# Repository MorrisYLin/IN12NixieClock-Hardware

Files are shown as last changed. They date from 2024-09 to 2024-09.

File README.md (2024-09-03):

# IN-12A Nixie Clock Project
## Overview
This PCB contains driver circuitry to handle high-voltage nixie tubes, which allows for binary-coded decimal to select the lit digit and independent PWM dimming for each tube. It also handles power conversion from a 12V 2A wall adapter to 170V, 5V, and 3.3V rails for the nixie tubes, development board, and ICs respectively, and accomodates connections to an ESP8266 WiFi module and an EK-TM4C1294XL development board from TI. These were chosen due to their relevance in my courses, and the design may be easily adapted to smaller microcontrollers more fitting for a clock.
## Images
Final Result


Front Copper

FrontCu
Back Copper

BackCu
Main Schematic

NixieSchematic
Tube Driver Schematic

TubeController

3D Render
3DRender

## Files
All design was done through KiCAD 8.0, the `TaylorElectronics` folder includes the footprints & symbols for the TES High-voltage power supply as well as others that are not included in the KiCAD standard library. The `nixies_us` folder contains footprints and symbols for the nixie tubes, credit to [judge2005](https://github.com/judge2005/Eagle-and-KiCAD-Nixie-Libs/tree/master) from nixies.us.

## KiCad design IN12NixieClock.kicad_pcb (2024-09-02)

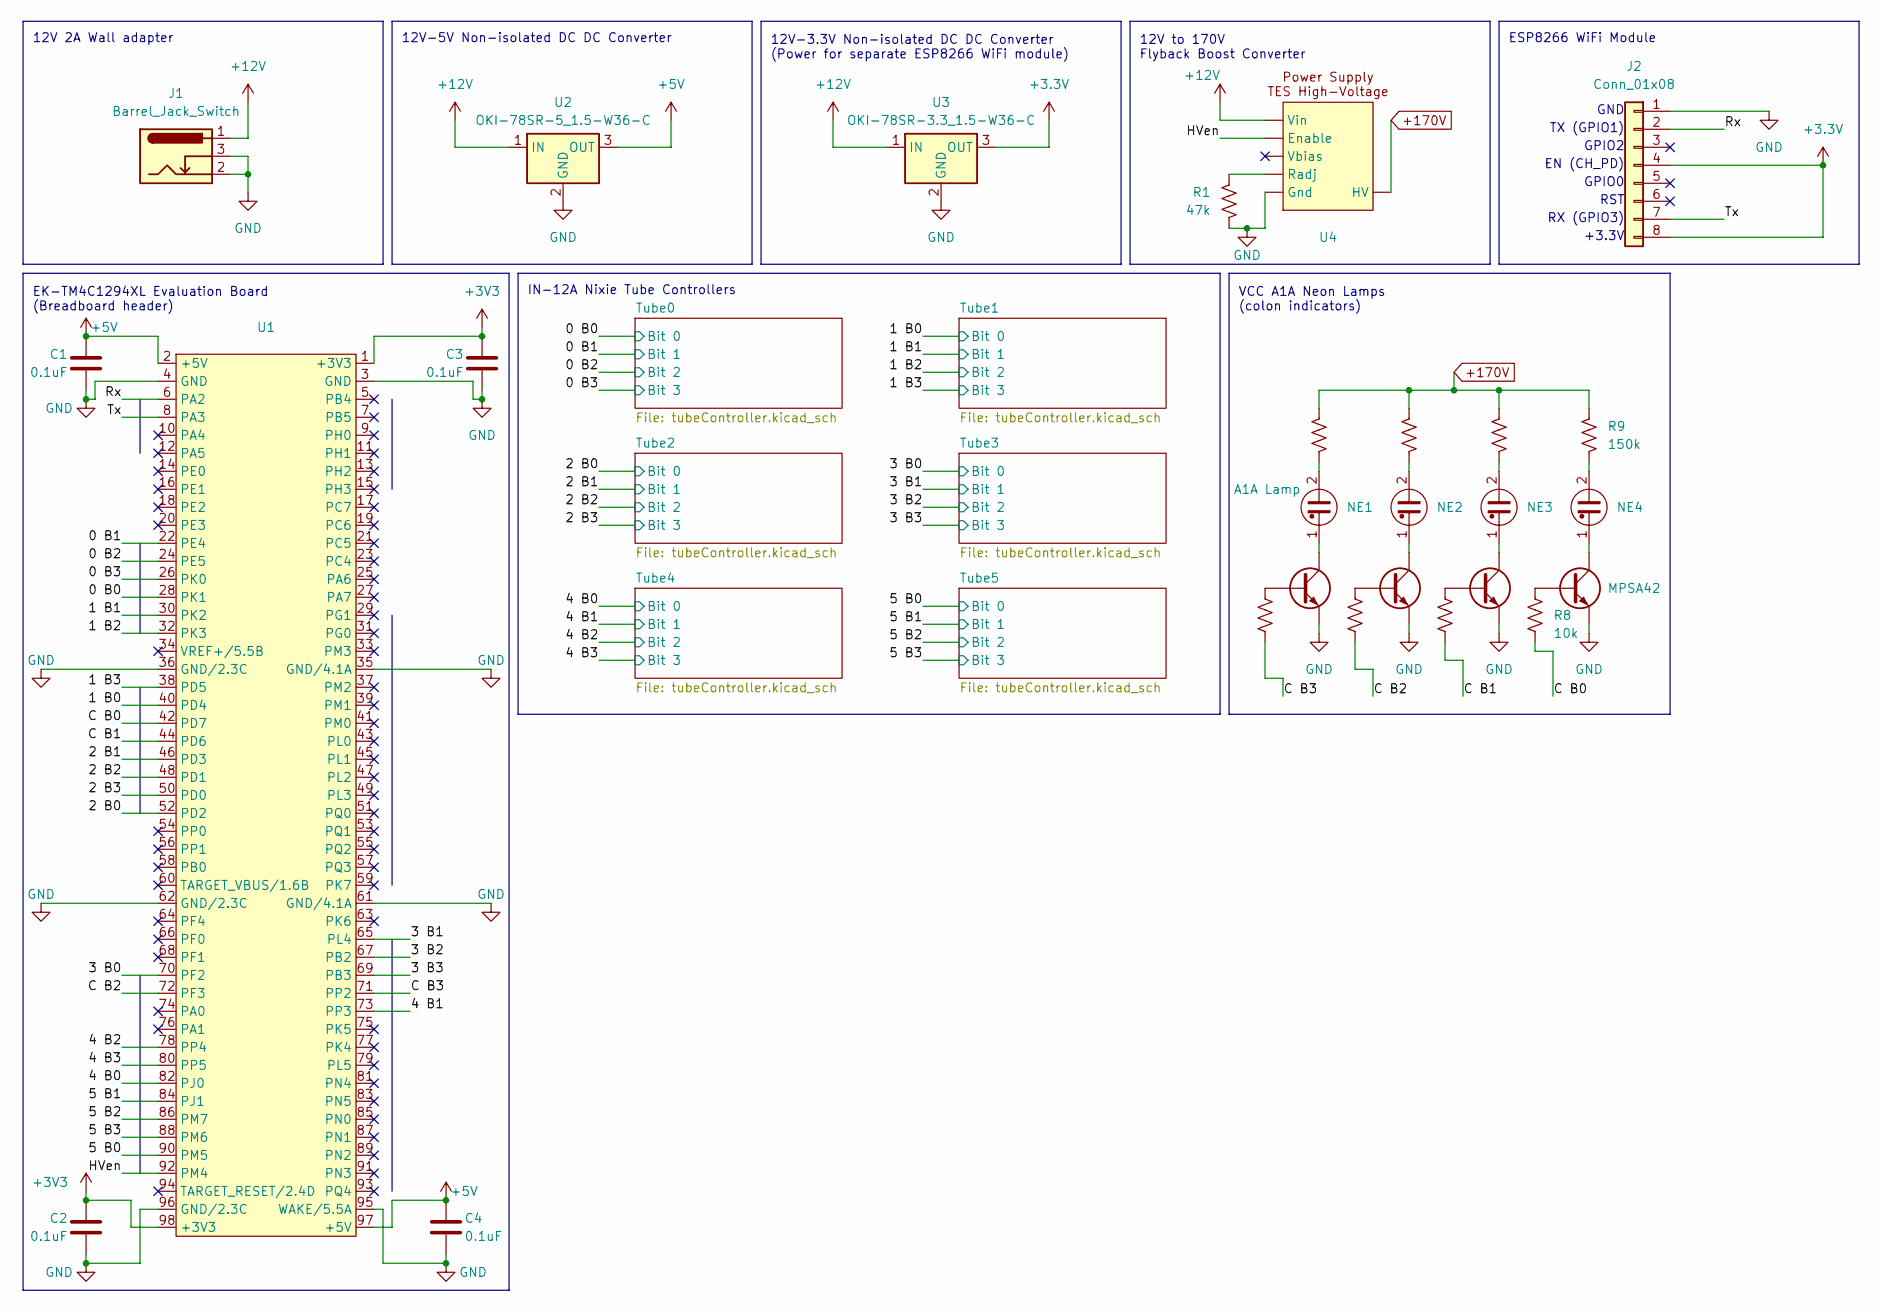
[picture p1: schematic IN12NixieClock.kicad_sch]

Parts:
C1, C2, C3, C4: 0.1uF; C_Disc_D5.0mm_W2.5mm_P5.00mm
J1: Barrel_Jack_Switch; 694106301002_1
J2: Conn_01x08; PinSocket_2x04_P2.54mm_Vertical
NE1: A1A Lamp; PinHeader_1x02_P2.54mm_Vertical
NE2, NE3, NE4: Lamp_Neon; PinHeader_1x02_P2.54mm_Vertical
Q1, Q2, Q3, Q4: MPSA42; TO-92_Inline
R1: 47k; R_Axial_DIN0309_L9.0mm_D3.2mm_P12.70mm_Horizontal
R2, R4, R6, R8: 10k; R_Axial_DIN0204_L3.6mm_D1.6mm_P5.08mm_Horizontal
R3, R5, R7, R9: 150k; R_Axial_DIN0309_L9.0mm_D3.2mm_P12.70mm_Horizontal
U1: X11 Breadboard Adapter Interface
U2: OKI-78SR-5_1.5-W36-C; Converter_DCDC_Murata_OKI-78SR_Vertical
U3: OKI-78SR-3.3_1.5-W36-C; Converter_DCDC_Murata_OKI-78SR_Vertical
U4: TES 1363 HVPS Vertical

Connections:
+3.3V: J2.4, J2.8, U3.3 (OUT); also elsewhere on the board
+3V3: C2.1, C3.1, U1.1 (+3V3), U1.98 (+3V3)
+5V: C1.1, C4.1, U1.2 (+5V), U1.97 (+5V), U2.3 (OUT)
+12V: J1.1, U2.1 (IN), U3.1 (IN), U4.Vin
+170V: R3.1, R5.1, R7.1, R9.1, U4.HV; also elsewhere on the board
/0 B0: U1.28 (PK1); also elsewhere on the board
/0 B1: U1.22 (PE4); also elsewhere on the board
/0 B2: U1.24 (PE5); also elsewhere on the board
/0 B3: U1.26 (PK0); also elsewhere on the board
/1 B0: U1.40 (PD4); also elsewhere on the board
/1 B1: U1.30 (PK2); also elsewhere on the board
/1 B2: U1.32 (PK3); also elsewhere on the board
/1 B3: U1.38 (PD5); also elsewhere on the board
/2 B0: U1.52 (PD2); also elsewhere on the board
/2 B1: U1.46 (PD3); also elsewhere on the board
/2 B2: U1.48 (PD1); also elsewhere on the board
/2 B3: U1.50 (PD0); also elsewhere on the board
/3 B0: U1.70 (PF2); also elsewhere on the board
/3 B1: U1.65 (PL4); also elsewhere on the board
/3 B2: U1.67 (PB2); also elsewhere on the board
/3 B3: U1.69 (PB3); also elsewhere on the board
/4 B0: U1.82 (PJ0); also elsewhere on the board
/4 B1: U1.73 (PP3); also elsewhere on the board
/4 B2: U1.78 (PP4); also elsewhere on the board
/4 B3: U1.80 (PP5); also elsewhere on the board
/5 B0: U1.90 (PM5); also elsewhere on the board
/5 B1: U1.84 (PJ1); also elsewhere on the board
/5 B2: U1.86 (PM7); also elsewhere on the board
/5 B3: U1.88 (PM6); also elsewhere on the board
/C B0: R8.2, U1.42 (PD7)
/C B1: R6.2, U1.44 (PD6)
/C B2: R4.2, U1.72 (PF3)
/C B3: R2.2, U1.71 (PP2)
/HVen: U1.92 (PM4), U4.Enable
/Rx: J2.2, U1.6 (PA2)
/Tx: J2.7, U1.8 (PA3)
GND: C1.2, C2.2, C3.2, C4.2, J1.2, J1.3, J2.1, Q1.1 (E), Q2.1 (E), Q3.1 (E), Q4.1 (E), R1.1, U1.3 (GND), U1.4 (GND), U1.35 (GND/4.1A), U1.36 (GND/2.3C), U1.61 (GND/4.1A), U1.62 (GND/2.3C), U1.95 (WAKE/5.5A), U1.96 (GND/2.3C), U2.2 (GND), U3.2 (GND), U4.Gnd; also elsewhere on the board
unnamed: NE1.2, R3.2
unnamed: NE2.2, R5.2
unnamed: NE3.2, R7.2
unnamed: NE4.2, R9.2
unnamed: Q1.2 (B), R2.1
unnamed: NE1.1, Q1.3 (C)
unnamed: Q2.2 (B), R4.1
unnamed: NE2.1, Q2.3 (C)
unnamed: Q3.2 (B), R6.1
unnamed: NE3.1, Q3.3 (C)
unnamed: Q4.2 (B), R8.1
unnamed: NE4.1, Q4.3 (C)
unnamed: R1.2, U4.Radj

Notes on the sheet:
GND
TX (GPIO1)
GPIO2
RX (GPIO3)
12V to 170V Flyback Boost Converter
IN-12A Nixie Tube Controllers
+3.3V
ESP8266 WiFi Module
EN (CH_PD)
EK-TM4C1294XL Evaluation Board (Breadboard header)
GPIO0
12V 2A Wall adapter
12V-5V Non-isolated DC DC Converter
RST
12V-3.3V Non-isolated DC DC Converter (Power for separate ESP8266 WiFi module)
VCC A1A Neon Lamps (colon indicators)

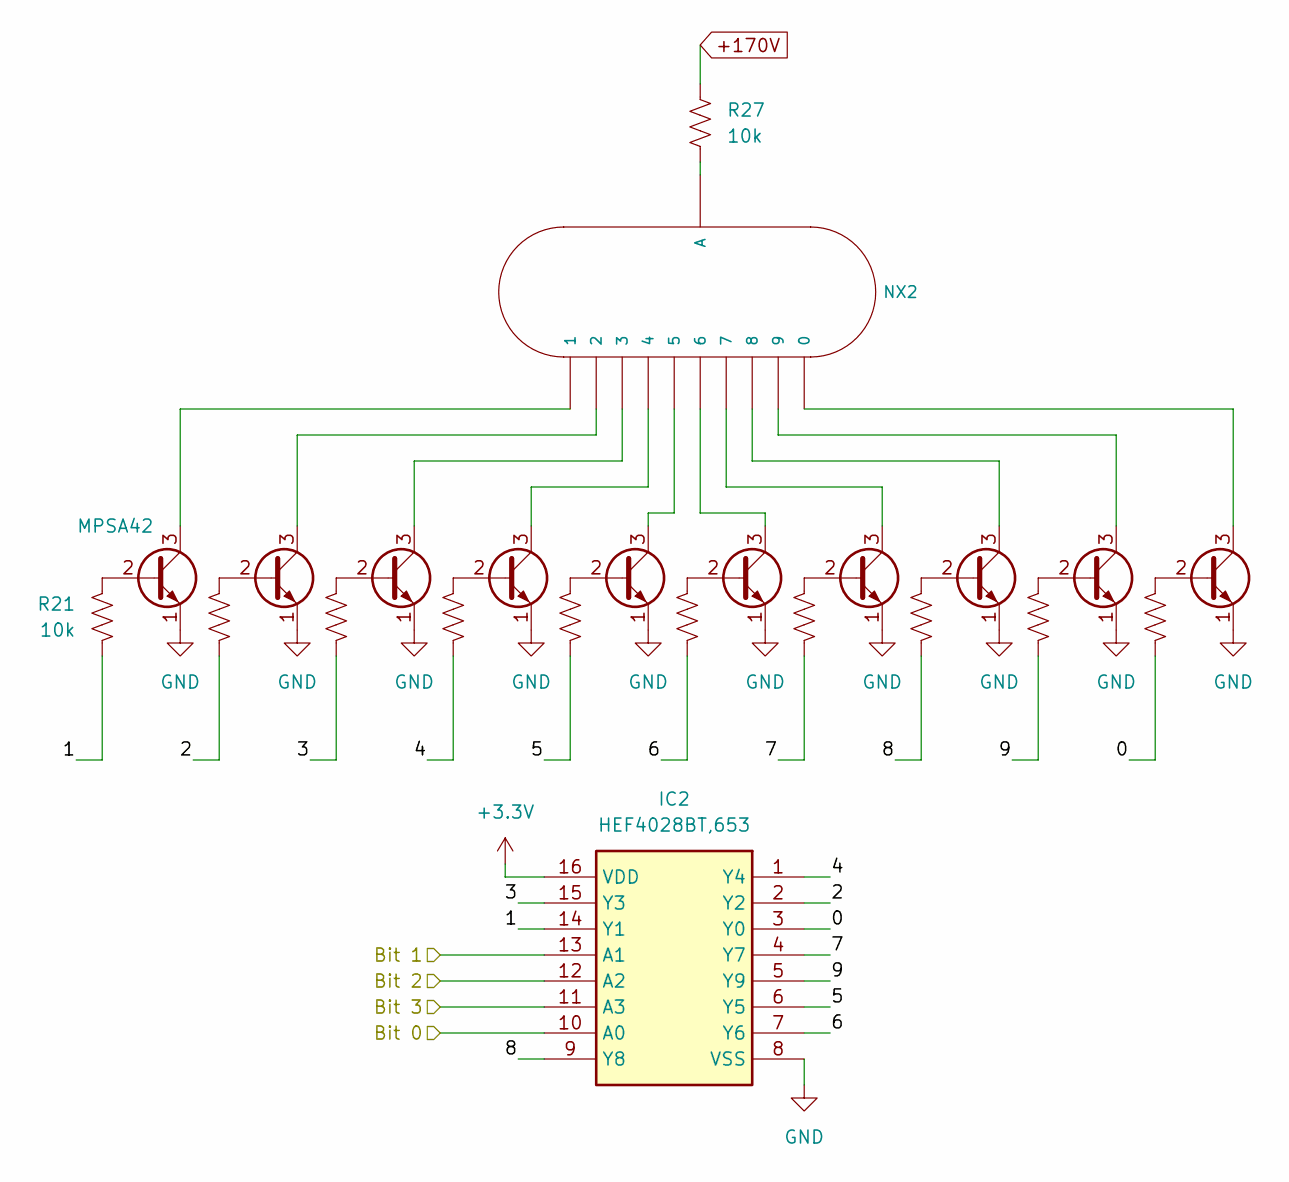
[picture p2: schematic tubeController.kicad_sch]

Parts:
IC2: HEF4028BT,653; HEF4028BT653; Mouser Part Number 771-HEF4028BTD-T
NX2: IN-12A; nixies-us-IN-12-DSUB
Q15, Q16, Q17, Q18, Q19, Q20, Q21, Q22, Q23, Q24: MPSA42; TO-92_Inline
R21, R22, R23, R24, R25, R26, R28, R29, R30, R31: 10k; R_Axial_DIN0204_L3.6mm_D1.6mm_P5.08mm_Horizontal
R27: 10k; R_Axial_DIN0309_L9.0mm_D3.2mm_P12.70mm_Horizontal

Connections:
+3.3V: IC2.16 (VDD); also elsewhere on the board
+170V: R27.1; also elsewhere on the board
/1 B0: IC2.10 (A0); also elsewhere on the board
/1 B1: IC2.13 (A1); also elsewhere on the board
/1 B2: IC2.12 (A2); also elsewhere on the board
/1 B3: IC2.11 (A3); also elsewhere on the board
/Tube1/0: IC2.3 (Y0), R31.2
/Tube1/1: IC2.14 (Y1), R21.2
/Tube1/2: IC2.2 (Y2), R22.2
/Tube1/3: IC2.15 (Y3), R23.2
/Tube1/4: IC2.1 (Y4), R24.2
/Tube1/5: IC2.6 (Y5), R25.2
/Tube1/6: IC2.7 (Y6), R26.2
/Tube1/7: IC2.4 (Y7), R28.2
/Tube1/8: IC2.9 (Y8), R29.2
/Tube1/9: IC2.5 (Y9), R30.2
GND: IC2.8 (VSS), Q15.1 (E), Q16.1 (E), Q17.1 (E), Q18.1 (E), Q19.1 (E), Q20.1 (E), Q21.1 (E), Q22.1 (E), Q23.1 (E), Q24.1 (E); also elsewhere on the board
unnamed: NX2.A, R27.2
unnamed: Q15.2 (B), R21.1
unnamed: NX2.1, Q15.3 (C)
unnamed: Q16.2 (B), R22.1
unnamed: NX2.2, Q16.3 (C)
unnamed: Q17.2 (B), R23.1
unnamed: NX2.3, Q17.3 (C)
unnamed: Q18.2 (B), R24.1
unnamed: NX2.4, Q18.3 (C)
unnamed: Q19.2 (B), R25.1
unnamed: NX2.5, Q19.3 (C)
unnamed: Q20.2 (B), R26.1
unnamed: NX2.6, Q20.3 (C)
unnamed: Q21.2 (B), R28.1
unnamed: NX2.7, Q21.3 (C)
unnamed: Q22.2 (B), R29.1
unnamed: NX2.8, Q22.3 (C)
unnamed: Q23.2 (B), R30.1
unnamed: NX2.9, Q23.3 (C)
unnamed: Q24.2 (B), R31.1
unnamed: NX2.0, Q24.3 (C)

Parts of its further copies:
IC1, IC3, IC4, IC5, IC6: HEF4028BT,653; HEF4028BT653; Mouser Part Number 771-HEF4028BTD-T
NX1, NX3, NX4, NX5, NX6: IN-12A; nixies-us-IN-12-DSUB
Q5, Q6, Q7, Q8, Q9, Q10, Q11, Q12, Q13, Q14, Q25, Q26, Q27, Q28, Q29, Q30, Q31, Q32, Q33, Q34, Q35, Q36, Q37, Q38, Q39, Q40, Q41, Q42, Q43, Q44, Q45, Q46, Q47, Q48, Q49, Q50, Q51, Q52, Q53, Q54, Q55, Q56, Q57, Q58, Q59, Q60, Q61, Q62, Q63, Q64: MPSA42; TO-92_Inline
R10, R11, R12, R13, R14, R15, R17, R18, R19, R20, R32, R33, R34, R35, R36, R37, R39, R40, R41, R42, R43, R44, R45, R46, R47, R48, R50, R51, R52, R53, R54, R55, R56, R57, R58, R59, R61, R62, R63, R64, R65, R66, R67, R68, R69, R70, R72, R73, R74, R75: 10k; R_Axial_DIN0204_L3.6mm_D1.6mm_P5.08mm_Horizontal
R16, R38, R49, R60, R71: 10k; R_Axial_DIN0309_L9.0mm_D3.2mm_P12.70mm_Horizontal

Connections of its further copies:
+3.3V: IC1.16 (VDD), IC3.16 (VDD), IC4.16 (VDD), IC5.16 (VDD), IC6.16 (VDD); also elsewhere on the board
+170V: R16.1, R38.1, R49.1, R60.1, R71.1; also elsewhere on the board
/0 B0: IC1.10 (A0); also elsewhere on the board
/0 B1: IC1.13 (A1); also elsewhere on the board
/0 B2: IC1.12 (A2); also elsewhere on the board
/0 B3: IC1.11 (A3); also elsewhere on the board
/2 B0: IC3.10 (A0); also elsewhere on the board
/2 B1: IC3.13 (A1); also elsewhere on the board
/2 B2: IC3.12 (A2); also elsewhere on the board
/2 B3: IC3.11 (A3); also elsewhere on the board
/3 B0: IC4.10 (A0); also elsewhere on the board
/3 B1: IC4.13 (A1); also elsewhere on the board
/3 B2: IC4.12 (A2); also elsewhere on the board
/3 B3: IC4.11 (A3); also elsewhere on the board
/4 B0: IC5.10 (A0); also elsewhere on the board
/4 B1: IC5.13 (A1); also elsewhere on the board
/4 B2: IC5.12 (A2); also elsewhere on the board
/4 B3: IC5.11 (A3); also elsewhere on the board
/5 B0: IC6.10 (A0); also elsewhere on the board
/5 B1: IC6.13 (A1); also elsewhere on the board
/5 B2: IC6.12 (A2); also elsewhere on the board
/5 B3: IC6.11 (A3); also elsewhere on the board
/Tube0/0: IC1.3 (Y0), R20.2
/Tube0/1: IC1.14 (Y1), R10.2
/Tube0/2: IC1.2 (Y2), R11.2
/Tube0/3: IC1.15 (Y3), R12.2
/Tube0/4: IC1.1 (Y4), R13.2
/Tube0/5: IC1.6 (Y5), R14.2
/Tube0/6: IC1.7 (Y6), R15.2
/Tube0/7: IC1.4 (Y7), R17.2
/Tube0/8: IC1.9 (Y8), R18.2
/Tube0/9: IC1.5 (Y9), R19.2
/Tube2/0: IC3.3 (Y0), R42.2
/Tube2/1: IC3.14 (Y1), R32.2
/Tube2/2: IC3.2 (Y2), R33.2
/Tube2/3: IC3.15 (Y3), R34.2
/Tube2/4: IC3.1 (Y4), R35.2
/Tube2/5: IC3.6 (Y5), R36.2
/Tube2/6: IC3.7 (Y6), R37.2
/Tube2/7: IC3.4 (Y7), R39.2
/Tube2/8: IC3.9 (Y8), R40.2
/Tube2/9: IC3.5 (Y9), R41.2
/Tube3/0: IC4.3 (Y0), R53.2
/Tube3/1: IC4.14 (Y1), R43.2
/Tube3/2: IC4.2 (Y2), R44.2
/Tube3/3: IC4.15 (Y3), R45.2
/Tube3/4: IC4.1 (Y4), R46.2
/Tube3/5: IC4.6 (Y5), R47.2
/Tube3/6: IC4.7 (Y6), R48.2
/Tube3/7: IC4.4 (Y7), R50.2
/Tube3/8: IC4.9 (Y8), R51.2
/Tube3/9: IC4.5 (Y9), R52.2
/Tube4/0: IC5.3 (Y0), R64.2
/Tube4/1: IC5.14 (Y1), R54.2
/Tube4/2: IC5.2 (Y2), R55.2
/Tube4/3: IC5.15 (Y3), R56.2
/Tube4/4: IC5.1 (Y4), R57.2
/Tube4/5: IC5.6 (Y5), R58.2
/Tube4/6: IC5.7 (Y6), R59.2
/Tube4/7: IC5.4 (Y7), R61.2
/Tube4/8: IC5.9 (Y8), R62.2
/Tube4/9: IC5.5 (Y9), R63.2
/Tube5/0: IC6.3 (Y0), R75.2
/Tube5/1: IC6.14 (Y1), R65.2
/Tube5/2: IC6.2 (Y2), R66.2
/Tube5/3: IC6.15 (Y3), R67.2
/Tube5/4: IC6.1 (Y4), R68.2
/Tube5/5: IC6.6 (Y5), R69.2
/Tube5/6: IC6.7 (Y6), R70.2
/Tube5/7: IC6.4 (Y7), R72.2
/Tube5/8: IC6.9 (Y8), R73.2
/Tube5/9: IC6.5 (Y9), R74.2
GND: IC1.8 (VSS), IC3.8 (VSS), IC4.8 (VSS), IC5.8 (VSS), IC6.8 (VSS), Q5.1 (E), Q6.1 (E), Q7.1 (E), Q8.1 (E), Q9.1 (E), Q10.1 (E), Q11.1 (E), Q12.1 (E), Q13.1 (E), Q14.1 (E), Q25.1 (E), Q26.1 (E), Q27.1 (E), Q28.1 (E), Q29.1 (E), Q30.1 (E), Q31.1 (E), Q32.1 (E), Q33.1 (E), Q34.1 (E), Q35.1 (E), Q36.1 (E), Q37.1 (E), Q38.1 (E), Q39.1 (E), Q40.1 (E), Q41.1 (E), Q42.1 (E), Q43.1 (E), Q44.1 (E), Q45.1 (E), Q46.1 (E), Q47.1 (E), Q48.1 (E), Q49.1 (E), Q50.1 (E), Q51.1 (E), Q52.1 (E), Q53.1 (E), Q54.1 (E), Q55.1 (E), Q56.1 (E), Q57.1 (E), Q58.1 (E), Q59.1 (E), Q60.1 (E), Q61.1 (E), Q62.1 (E), Q63.1 (E), Q64.1 (E); also elsewhere on the board
unnamed: NX1.A, R16.2
unnamed: NX3.A, R38.2
unnamed: NX4.A, R49.2
unnamed: NX5.A, R60.2
unnamed: NX6.A, R71.2
unnamed: Q5.2 (B), R10.1
unnamed: NX1.1, Q5.3 (C)
unnamed: Q6.2 (B), R11.1
unnamed: NX1.2, Q6.3 (C)
unnamed: Q7.2 (B), R12.1
unnamed: NX1.3, Q7.3 (C)
unnamed: Q8.2 (B), R13.1
unnamed: NX1.4, Q8.3 (C)
unnamed: Q9.2 (B), R14.1
unnamed: NX1.5, Q9.3 (C)
unnamed: Q10.2 (B), R15.1
unnamed: NX1.6, Q10.3 (C)
unnamed: Q11.2 (B), R17.1
unnamed: NX1.7, Q11.3 (C)
unnamed: Q12.2 (B), R18.1
unnamed: NX1.8, Q12.3 (C)
unnamed: Q13.2 (B), R19.1
unnamed: NX1.9, Q13.3 (C)
unnamed: Q14.2 (B), R20.1
unnamed: NX1.0, Q14.3 (C)
unnamed: Q25.2 (B), R32.1
unnamed: NX3.1, Q25.3 (C)
unnamed: Q26.2 (B), R33.1
unnamed: NX3.2, Q26.3 (C)
unnamed: Q27.2 (B), R34.1
unnamed: NX3.3, Q27.3 (C)
unnamed: Q28.2 (B), R35.1
unnamed: NX3.4, Q28.3 (C)
unnamed: Q29.2 (B), R36.1
unnamed: NX3.5, Q29.3 (C)
unnamed: Q30.2 (B), R37.1
unnamed: NX3.6, Q30.3 (C)
unnamed: Q31.2 (B), R39.1
unnamed: NX3.7, Q31.3 (C)
unnamed: Q32.2 (B), R40.1
unnamed: NX3.8, Q32.3 (C)
unnamed: Q33.2 (B), R41.1
unnamed: NX3.9, Q33.3 (C)
unnamed: Q34.2 (B), R42.1
unnamed: NX3.0, Q34.3 (C)
unnamed: Q35.2 (B), R43.1
unnamed: NX4.1, Q35.3 (C)
unnamed: Q36.2 (B), R44.1
unnamed: NX4.2, Q36.3 (C)
unnamed: Q37.2 (B), R45.1
unnamed: NX4.3, Q37.3 (C)
unnamed: Q38.2 (B), R46.1
unnamed: NX4.4, Q38.3 (C)
unnamed: Q39.2 (B), R47.1
unnamed: NX4.5, Q39.3 (C)
unnamed: Q40.2 (B), R48.1
unnamed: NX4.6, Q40.3 (C)
unnamed: Q41.2 (B), R50.1
unnamed: NX4.7, Q41.3 (C)
unnamed: Q42.2 (B), R51.1
unnamed: NX4.8, Q42.3 (C)
unnamed: Q43.2 (B), R52.1
unnamed: NX4.9, Q43.3 (C)
unnamed: Q44.2 (B), R53.1
unnamed: NX4.0, Q44.3 (C)
unnamed: Q45.2 (B), R54.1
unnamed: NX5.1, Q45.3 (C)
unnamed: Q46.2 (B), R55.1
unnamed: NX5.2, Q46.3 (C)
unnamed: Q47.2 (B), R56.1
unnamed: NX5.3, Q47.3 (C)
unnamed: Q48.2 (B), R57.1
unnamed: NX5.4, Q48.3 (C)
unnamed: Q49.2 (B), R58.1
unnamed: NX5.5, Q49.3 (C)
unnamed: Q50.2 (B), R59.1
unnamed: NX5.6, Q50.3 (C)
unnamed: Q51.2 (B), R61.1
unnamed: NX5.7, Q51.3 (C)
unnamed: Q52.2 (B), R62.1
unnamed: NX5.8, Q52.3 (C)
unnamed: Q53.2 (B), R63.1
unnamed: NX5.9, Q53.3 (C)
unnamed: Q54.2 (B), R64.1
unnamed: NX5.0, Q54.3 (C)
unnamed: Q55.2 (B), R65.1
unnamed: NX6.1, Q55.3 (C)
unnamed: Q56.2 (B), R66.1
unnamed: NX6.2, Q56.3 (C)
unnamed: Q57.2 (B), R67.1
unnamed: NX6.3, Q57.3 (C)
unnamed: Q58.2 (B), R68.1
unnamed: NX6.4, Q58.3 (C)
unnamed: Q59.2 (B), R69.1
unnamed: NX6.5, Q59.3 (C)
unnamed: Q60.2 (B), R70.1
unnamed: NX6.6, Q60.3 (C)
unnamed: Q61.2 (B), R72.1
unnamed: NX6.7, Q61.3 (C)
unnamed: Q62.2 (B), R73.1
unnamed: NX6.8, Q62.3 (C)
unnamed: Q63.2 (B), R74.1
unnamed: NX6.9, Q63.3 (C)
unnamed: Q64.2 (B), R75.1
unnamed: NX6.0, Q64.3 (C)

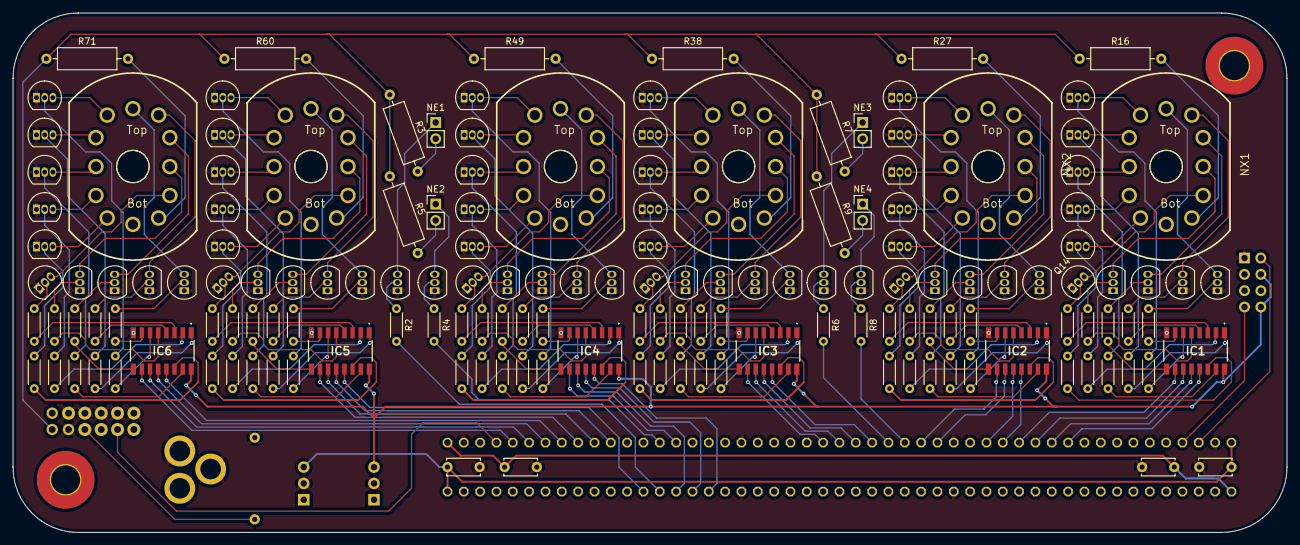
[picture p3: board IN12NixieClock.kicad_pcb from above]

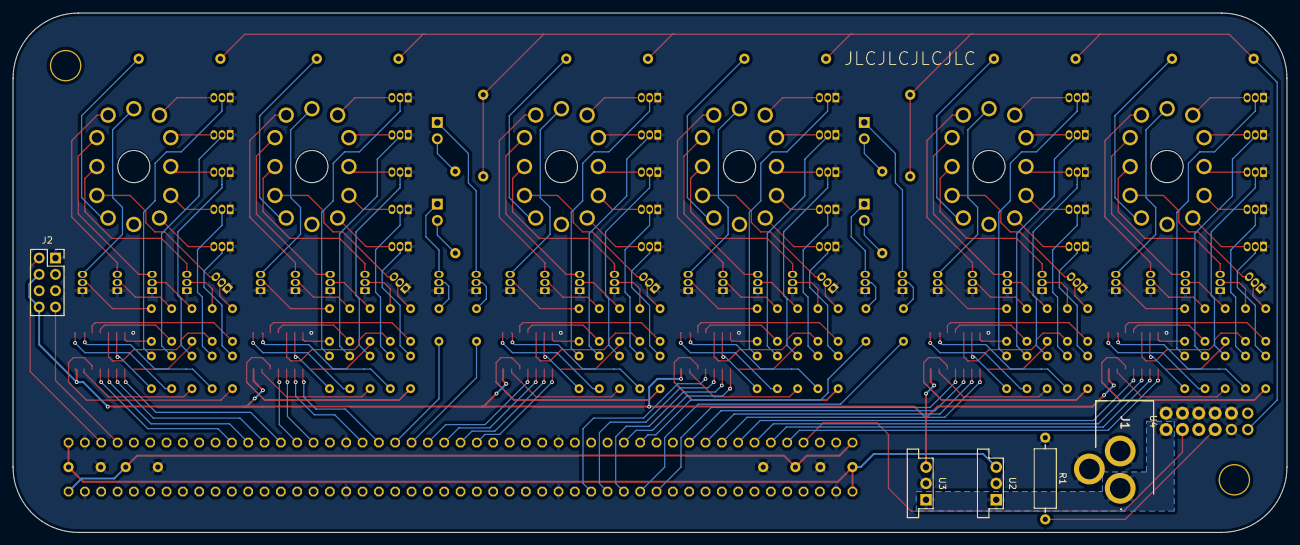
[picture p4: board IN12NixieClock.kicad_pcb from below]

Board: 2 copper layers, 198.1 x 80.8 mm, 165 parts (6 on the bottom side), 236 nets.
